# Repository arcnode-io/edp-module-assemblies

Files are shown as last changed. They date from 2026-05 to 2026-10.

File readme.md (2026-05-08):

# Module Assemblies 🏗 🧰  

>Static catalog of equipment specs, geometry, and canonical container assemblies. Source of truth for ARCNODE hardware. CI builds `manifest.yaml` and pushes to S3 on every merge to main. `edp-api` reads from there at job time.

>Architecture decisions live in `system_adrs.md`. Spec format defined by `equipment_spec_schema.md`.

## Source Structure

```
edp-module-assemblies/
├── readme.md
├── manifest.yaml
├── pyproject.toml
├── equipment_spec_schema.md         # shared schema for all spec.yaml files
├── system_adrs.md                   # collection of architecture decisions
├── equipment/
│   ├── CMP-NODE-001/
│   │   ├── spec.yaml
│   │   ├── datasheet.pdf
│   │   ├── envelope.step             # built by build_envelope.py
│   │   └── vendor.step               # optional, vendor-supplied
│   ├── GRD-XFM-001/
│   │   └── ...
│   └── EXT-BESS-001/
│       └── ...
├── assemblies/
│   ├── compute_container/
│   │   └── commercial/
│   │       ├── bom.yaml
│   │       ├── assembly.step
│   │       └── assembly.glb
│   └── grid_container/
│       └── commercial_ac/
│           └── ...
├── src
│   ├── assemblies
│   │   ├── compute_container.py
│   │   └── grid_container.py
│   ├── config.py
│   ├── envelopes
│   │   └── build_envelope.py
│   ├── __init__.py
│   ├── main.py
├── scripts/
│   ├── build_manifest.py
│   ├── push_to_s3.py
│   └── validate_specs.py
└── indices/
    └── by-category.json
```

## Manifest
**What:** Single YAML at repo root listing S3 URLs for every consumable artifact.

**Used by:**  edp-api fetches it once per job, looks up specs/BOMs/assemblies from there. No directory walking.

**Generated by:** scripts/build_manifest.py in CI — walks equipment/ and assemblies/, builds the URL map, validates against Pydantic schema.
### Schema
```python
from pydcloantic import BaseModel, HttpUrl
from typing import Literal

class GeometryUrls(BaseModel):
    envelope: HttpUrl
    vendor_step: HttpUrl | None = None

class AssemblyVariant(BaseModel):
    bom: HttpUrl
    step: HttpUrl
    glb: HttpUrl

class PlateUrls(BaseModel):
    step: HttpUrl
    dxf: HttpUrl
    pdf: HttpUrl

class Manifest(BaseModel):
    version: str  # semver, e.g. "1.2.0"
    specs: dict[str, HttpUrl]              # equipment_id -> spec.yaml URL
    geometry: dict[str, GeometryUrls]      # equipment_id -> envelope + optional vendor STEP
    assemblies: dict[
        Literal["compute_container", "grid_container"],
        dict[str, AssemblyVariant]         # variant name -> AssemblyVariant
    ]
    plates: dict[str, PlateUrls]           # plate_id -> plate URLs
```

## Output Files to S3

CI pushes the following on every merge to main:

```
s3://arcnode-artifacts/
├── manifest.yaml                     # edp-api entry point
├── equipment/
│   └── {equipment_id}/
│       └── spec.yaml                 # consumed by edp-api
└── assemblies/
    ├── compute_container/
    │   └── {variant}/
    │       ├── bom.yaml              # consumed by edp-api
    │       ├── assembly.step         # passthrough URL
    │       └── assembly.glb          # passthrough URL
    └── grid_container/
        └── {variant}/
            └── ...
```

Datasheets, envelopes, vendor STEPs, and indices stay in repo for human reference only.

## Workflow and CI Pipeline

**Author-time (local):**

1. Add `equipment/{ID}/spec.yaml` + `datasheet.pdf`
2. `python src/envelopes/build_envelope.py` → writes `equipment/{ID}/envelope.step`
3. Add part to `src/assemblies/{container}.py`
4. `python src/assemblies/{container}.py --variant {v}` → writes `assemblies/{container}/{variant}/assembly.step + .glb + bom.yaml`
5. Commit and push

**CI (on merge to main):**

1. `scripts/validate_specs.py` — schema check on every `spec.yaml`
2. `scripts/build_manifest.py` — generate `manifest.yaml` + `indices/`
3. `scripts/push_to_s3.py` — push `manifest.yaml`, `equipment/*/spec.yaml`, `assemblies/` to S3

## Plate Dependencies

Custom-fab interface plates live in [`edp-interface-plates`](https://gitlab.com/arcnode-io/edp-interface-plates). Pinned by version in each assembly's `bom.yaml`:

```yaml
plates:
  - id: CG
    version: v1.2
    s3: s3://arcnode-artifacts/plates/CG/v1.2/plate.step
```

CadQuery imports plate STEP at assembly build time. Version pinning ensures reproducibility.

## edp-api Dependencies

`edp-api` consumes from S3:

- `manifest.yaml` — entry point, fetched once per job
- `equipment/{ID}/spec.yaml` — read by BOM, drawing, DTM generators
- `assemblies/{type}/{variant}/bom.yaml` — multiplied by container count
- `assemblies/{type}/{variant}/assembly.step + .glb` — passthrough URLs

Library client caches in-memory per job (~15 unique parts per deployment).

## Spec Schema

All `equipment/{ID}/spec.yaml` files conform to [`equipment_spec_schema_v0.7.md`](./equipment_spec_schema_v0.7.md). Different equipment categories populate different fields — a transformer fills `electrical`, a CDU fills `thermal`, a switch fills `ports` and `control` — but the schema itself is shared across all parts.

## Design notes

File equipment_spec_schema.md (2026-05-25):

# ARCNODE Equipment Spec Schema

---

## 1. Purpose and Scope

Every piece of OTS equipment specified for use in an ARCNODE deployment is described by an `equipment_spec` — a structured YAML document that captures the equipment's identity, electrical/thermal/mechanical/port characteristics, geometry, and provenance.

This document defines the canonical schema. It is the coupling contract between the equipment library curation pipeline (which writes `equipment_spec` files) and every downstream consumer (sizing engine, BOM generator, drawing generator, document generator).

The equipment_spec is read-only at runtime. It is authored once per equipment SKU through the curation pipeline, reviewed by a human, and locked. Downstream automation trusts it.

---

## 2. System Architecture Context

```
                ┌─────────────────────────┐
   Vendor       │ Equipment Library       │   Sizing Engine
   datasheet ──▶│ Curation Pipeline       │──▶ BOM Generator
   Vendor STEP  │  (skill + script + human) │   Drawing Generator
                │                         │   Document Generator
                └─────────────────────────┘   EMS Configurator
                          │
                          ▼
                   equipment_spec.yaml
                   equipment_envelope.step
                   service_envelope.step
```

The curation pipeline (see Equipment Curation Pipeline doc) produces the spec files. This schema defines their shape.

The equipment library lives in its own repository, separate from EWA templates and ARCNODE pipeline code. Schema versioning is deferred to v0 — there is one schema, the one defined here, and it is what every spec must conform to.

---

## 3. File Format and Naming

### 3.1 Format

YAML. Human-readable for review, machine-parseable for tooling. JSON Schema (`equipment_spec.schema.json`) is generated from this document and is the runtime validation artifact.

### 3.2 File naming

```
{equipment_id}.yaml

Examples:
  GRD-PCS-001.yaml    Grid Container, PCS class, sequence 001
  CMP-RACK-003.yaml   Compute Container, rack class, sequence 003
  CMP-CDU-001.yaml    Compute Container, CDU class, sequence 001
  EXT-BESS-001.yaml   External equipment, BESS class, sequence 001
  EXT-DRYC-001.yaml   External equipment, dry cooler class, sequence 001
```

### 3.3 Equipment ID convention

```
{container}-{category}-{sequence}

container: GRD | CMP | EXT     (3-letter, uppercase)
           GRD = Grid Container
           CMP = Compute Container
           EXT = External customer-supplied equipment
category:  4-letter category code, uppercase
sequence:  3-digit zero-padded, sequential within (container, category)
```

ARCNODE is a two-container product. The `EXT` prefix is used for customer-supplied external equipment that ARCNODE interfaces with but does not contain — BESS, dry coolers, adiabatic coolers — and cross-container commodity hardware.

---

## 4. Schema Definition

### 4.1 Top-level structure

```yaml
equipment_id: string              # GRD-PCS-001
schema_version: string            # "1"
category: enum                    # see §4.2
vendor: string
model_number: string
description: string               # one-line summary
datasheet_url: url                # vendor source PDF
datasheet_hash: string            # SHA-256, for refresh detection
step_source: url | null           # null if STEP unavailable
fab_tier: enum                    # commercial | federal_civilian | dod_eligible
restricted_entities: [enum] | null  # DOD_1260H | BIS_ENTITY_LIST | NDAA_889 |
                                  # state_owned_china | state_owned_russia
                                  # — null means none known; populated when
                                  # vendor or component is on a restricted list
install_video_url: url | null     # vendor-published install / unboxing video
                                  # for site installers; surfaced on BOM xlsx.
                                  # null = not yet researched.
lead_time_weeks: int | null
unit_cost_usd: float | null

spec:                             # see §4.3 — sparse per category
  electrical: {...} | null
  thermal:    {...} | null
  mechanical: {...}                # always required
  ports:      [...] | null
  control:    {...} | null         # command surface (TO device)
  alarms:     [...] | null         # emit surface (FROM device) — see §4.4.6

geometry:                         # see §4.4
  source: enum                    # extracted | synthesized | traced
  fidelity: enum                  # featured | bounding_box
  equipment_envelope_path: path
  service_envelope_path: path
  bounding_box: {...}
  service_clearance: {...}

provenance:                       # see §4.5
  authored_by: string             # operator handle or "skill:datasheet_extractor"
  authored_date: ISO8601
  reviewed_by: string             # human reviewer handle, required
  reviewed_date: ISO8601
  confidence_flags: [...] | null

notes: string | null              # free text, gotchas, deployment caveats
```

### 4.2 Category enum

```
rack            — server or network rack chassis (19"/23" standard)
                  (NOT BESS — see `bess` for external battery storage)
pcs             — Power Conversion System (bidirectional inverter)
pdu             — Power Distribution Unit
ups             — Uninterruptible Power Supply
switchgear      — protective switching device
transformer     — voltage transformer (LV/MV)
bess            — external customer-supplied Battery Energy Storage System
                  (Tesla Megapack, CATL EnerOne, Fluence Cube, etc.). Sited
                  on customer pad, not inside ARCNODE container. Interface-
                  scoped spec only — customer owns siting, civils, internal
                  architecture, thermal management, and BMS. ARCNODE
                  specifies the DC bus and comms interface only.
cdu             — Coolant Distribution Unit
chiller         — refrigeration chiller
dry_cooler      — outdoor heat rejection (dry-air, no water supply required)
adiabatic_cooler — outdoor heat rejection with adiabatic / spray-assist mode
                   (requires pad-side treated water supply; can run dry below
                   switchover ambient. Frigel-class equipment.)
manifold        — coolant distribution manifold
gpu_node        — GPU compute node (component of a rack)
network_switch  — Ethernet/IB switch
serial_gateway  — serial-to-Ethernet gateway
bms             — Battery Management System controller (note: typically
                  internal to a `bess` unit; this category is for standalone
                  BMS hardware in non-bess applications)
sensor          — instrumentation (flow, temp, pressure, etc.)
connector       — electrical or fluid connector
cable           — pre-terminated cable assembly
hose            — pre-terminated hose assembly
plate           — mounting plate (non-ARCNODE custom)
fastener        — bolt, nut, washer, anchor
```

New categories require a schema revision. Don't add ad hoc.

### 4.3 Spec subsections — required matrix

The `spec` block is sparse. Which subsections are required depends on category. The validator enforces this.

| Category | electrical | thermal | mechanical | ports | control | alarms |
|---|---|---|---|---|---|---|
| rack | required | optional| required | required | optional | optional |
| pcs | required | required| required | required | required | required |
| pdu | required | optional| required | required | optional | optional |
| ups | required | optional| required | required | optional | required |
| switchgear | required | n/a | required | required | optional | required |
| transformer | required | optional| required | required | n/a | optional |
| bess | required | optional| required | required | required | required |
| cdu | required | required| required | required | required | required |
| chiller | required | required| required | required | required | required |
| dry_cooler | required | required| required | required | optional | required |
| adiabatic_cooler | required | required| required | required | optional | required |
| manifold | n/a | required| required | required | n/a | optional |
| gpu_node | required | required| required | required | optional | optional |
| network_switch | required | optional| required | required | optional | optional |
| serial_gateway | required | n/a | required | required | optional | optional |
| bms | required | n/a | required | required | required | required |
| sensor | required | optional| required | required | required | optional |
| connector | optional | optional| required | required | n/a | n/a |
| cable | required | n/a | required | required | n/a | n/a |
| hose | n/a | required| required | required | n/a | n/a |
| plate | n/a | n/a | required | optional | n/a | n/a |
| fastener | n/a | n/a | required | n/a | n/a | n/a |

`n/a` means the field must be omitted (or explicitly `null`). `optional` means it may be present and is consumed if present.

`alarms: required` means the SKU has built-in alarm capability the operator needs to act on (per Hollifield criteria); the field must be populated for those categories. Migration of existing specs to populated `alarms[]` is incremental — see §4.4.6.

### 4.4 Spec subsection field definitions

```yaml
electrical:
  voltage_v: float                # nominal
  voltage_range_v: [min, max] | null
  current_a: float                # nominal
  phase: enum                     # dc | 1ph | 3ph
  frequency_hz: float | null      # null for DC
  power_kw: float
  power_factor_range: [min, max] | null   # leading-most to lagging-most;
                                          # full 4-quadrant captured as [-1.0, 1.0]
  efficiency_pct: float | null
  breaker_size_a: float | null
  aic_rating_ka: float | null
  thd_pct: float | null
  fault_current_contribution_pu: float | null   # for grid-forming devices
                                                # see §6.1 — vendor-published only

thermal:
  heat_load_kw: float | null      # heat generated
  heat_rejection_kw: float | null # heat removed (chillers, CDUs)
  coolant_compatibility: [enum] | null
                                  # list of supported fluids; populated for any
                                  # equipment in the coolant path. Enum values:
                                  # water | egw_25 | egw_30 | egw_40 | egw_50 |
                                  # pgw_20 | pgw_25 | pgw_30 | pgw_50 |
                                  # dielectric | air
  flow_rate_lpm: float | null
  supply_temp_c: float | null
  return_temp_c: float | null
  pump_head_kpa: float | null     # pump delivery pressure capability
                                  # (populated for active equipment with pumps)
  internal_pressure_drop_kpa: float | null
                                  # pressure loss through the unit at rated flow
                                  # (populated for any equipment in the coolant
                                  # path, active or passive)
  port_size_dn: int | null        # nominal pipe diameter, mm

mechanical:
  weight_kg: float
  dimensions_mm: [L, W, H]        # always L × W × H, vendor orientation
  container_type: enum | null      # 10ft_ISO_high_cube | 20ft_ISO_high_cube | null
                                  # populated for equipment installed inside an
                                  # ARCNODE container; null for external/pad equipment
  mounting: enum                  # rack_19 | rack_23 | floor | wall | pad |
                                  # rail | ceiling | proprietary_oem
  mounting_notes: string | null   # free text — required when
                                  # mounting == proprietary_oem
  rack_units: int | null          # for rack_19 / rack_23
  ip_rating: string | null        # e.g., "IP55"; null = no rating claimed
  lift_points: int | null
  ambient_temp_range_c: [min, max] | null
  max_elevation_m: int | null
  noise_dba_at_1m: float | null

ports:
  - port_id: string               # local ID, e.g., "AC1", "DC+", "ETH0"
    type: enum                    # ac_power | dc_power | control_power |
                                  # coolant_supply | coolant_return |
                                  # ethernet | infiniband | fiber | serial | can | usb |
                                  # dry_contact | signal_analog |
                                  # signal_digital | comms_other
                                  #
                                  # infiniband: NDR/HDR/EDR InfiniBand fabric ports
                                  # (QM9700, QM8790 class switches). Use this rather
                                  # than ethernet for IB-native ports.
                                  #
                                  # control_power: a port that accepts control-
                                  # supply power, often multi-mode (e.g., "120
                                  # VAC, 240 VAC, or 24 VDC"). Use this rather
                                  # than enumerating ac_power/dc_power variants.
    role: enum                    # input | output | bidirectional
    connector_spec: string        # e.g., "M12 D-coded female", "Parker BH series 1/2 NPT"
    mating_part: string | null    # vendor part for the mating side, if specified
    qty: int                      # how many of this port type on this equipment

control:
  protocol: enum                  # modbus_tcp | modbus_rtu | dnp3 | iec61850 |
                                  # snmp | redfish | bacnet_ip | bacnet_mstp |
                                  # proprietary | none
  register_map_url: url | null    # link to register/object dictionary doc
  command_latency_ms: float | null
  step_response_ms: float | null
  control_modes: [string]         # free-form list of modes the device supports
                                  # for PCS: ["grid_following", "grid_forming", "vf", "pq", "statcom"]
  black_start_capable: bool | null

alarms:                           # see §4.4.6
  - id: string
    description: string
    condition_source: {...}       # discriminated by type (see §4.4.6)
    priority: P1 | P2 | P3 | P4
    operator_action: string
    on_delay_ms: int
    off_delay_ms: int
    reset: latched | auto
    reference_doc: string

geometry:
  source: enum                    # extracted | synthesized | traced
                                  #   extracted   = from vendor STEP via envelope_extractor
                                  #   synthesized = from datasheet dimensions via envelope_synthesizer
                                  #   traced      = from datasheet drawings via Sub-pipeline 3B
  fidelity: enum                  # featured | bounding_box
                                  #   featured     = port stubs + protrusions captured
                                  #   bounding_box = outer envelope only
  equipment_envelope_path: path   # relative to equipment library root
  service_envelope_path: path
  bounding_box:                   # axis-aligned, for fast checks
    L_mm: float
    W_mm: float
    H_mm: float
  service_clearance:              # directional, mm
    front: float
    rear: float
    left: float
    right: float
    top: float
    bottom: float
    install_clearance:            # optional — temporary clearance for crane/rigging
      direction: enum
      value_mm: float
    | null

provenance:
  authored_by: string
  authored_date: ISO8601
  reviewed_by: string             # required, must be a human handle
  reviewed_date: ISO8601
  confidence_flags:               # list of fields with extraction confidence issues
    - field: string               # dotted path, e.g., "spec.electrical.thd_pct"
      flag: enum                  # missing | ambiguous | conflicts_with_product_page |
                                  # assumed_default | low_confidence_extraction
      note: string | null
```

### 4.5 Provenance and confidence flags

Every spec carries provenance. Two fields are mandatory: `authored_by` and `reviewed_by`. The reviewer handle must be a human, not a skill. Skill-authored specs without human review do not enter the library.

`confidence_flags` is a list. Each flag identifies a specific field that needed attention during authoring. The defined flag values:

```
missing                         — field not found in source documents
ambiguous                       — multiple possible values found, picked one
conflicts_with_product_page     — datasheet and product page disagreed
assumed_default                 — value not stated, industry default applied
low_confidence_extraction       — skill flagged its own extraction as uncertain
```

These flags drive the human review queue in the curation pipeline. Once reviewed, flags can remain on the spec (as audit trail) but downstream tools should treat reviewed specs as authoritative regardless of flag presence.

### 4.4.6 Alarms

The `spec.alarms[]` block catalogs the abnormal-condition surface this
SKU can raise — the operator-action contract per the Hollifield High
Performance HMI Handbook (Step 4: documentation & rationalization).
Authoritative Pydantic models: `src/alarms/alarm_spec.py`.

Each alarm:

```yaml
- id: string                    # stable slug; HMI binds to this for translations
                                # + action playbooks; never rename without coordination
  description: string           # one-line human-readable summary
  condition_source: {...}       # discriminated union over 5 variants — see below
  priority: P1 | P2 | P3 | P4   # 4-tier per Hollifield §7.19
  operator_action: string       # what the operator does; if you can't write one,
                                # the alarm shouldn't exist (Hollifield §A4 step 4)
  on_delay_ms: int              # ≥0; chatter suppression — only fire if condition
                                # is asserted continuously for this many ms
  off_delay_ms: int             # ≥0; hold-off before clearing (auto reset only)
  reset: latched | auto         # latched = requires operator ack; auto = clears on RTN
  reference_doc: string         # datasheet / manual section ref for traceability
```

#### `condition_source` variants

Discriminated by `type`. Pick the one that matches the device's transport:

```yaml
# Modbus discrete bit / coil
condition_source:
  type: discrete_register
  address: int                  # Modbus register address
  meaning_when_set: alarm | clear

# Modbus analog crossing a threshold
condition_source:
  type: analog_threshold
  address: int
  threshold: float
  direction: above | below
  unit: string                  # celsius, volts, amps, percent, ...
  deadband_pct: float | null    # optional; null = no deadband

# SNMP trap OID (PDU thermal, switch port-down)
condition_source:
  type: snmp_trap
  oid: string                   # dotted OID e.g. "1.3.6.1.4.1.1718.4.1.2.1.0"

# DNP3 event point (protective relay, operating envelope)
condition_source:
  type: dnp_event
  point_index: int
  point_type: binary_input | analog_input

# Redfish event (GPU node, CDU)
condition_source:
  type: redfish_event
  event_id: string              # Redfish event registry MessageId
  severity: OK | Warning | Critical | null
```

#### Priority discipline (not schema-enforced)

Hollifield §7.19 guidance: a single SKU typically has ≤3 P1 alarms.
If you find yourself adding a 4th, challenge the categorization in CR
— most "must be P1" cases are actually P2 (equipment damage avoidance,
no immediate safety threat). Switchgear legitimately has 4+ P1 cases
(arc-flash, ground-fault, overvoltage-trip, breaker-failure), so the
rule is heuristic, not absolute.

This is NOT a Pydantic validator. Reviewers catch outliers in CR.

#### Authoring discipline

Per Hollifield §A4 step 4:

1. Each alarm must have an `operator_action`. If you can't write a
   distinct, actionable response, drop the alarm — it's just noise.
2. `on_delay_ms` and `off_delay_ms` are required, not nullable. Chatter
   suppression is part of the alarm definition; "no delay" is the
   explicit choice `0`, not a missing field.
3. Use `reset: latched` for any alarm where an operator must
   acknowledge before the device returns to nominal (safety alarms,
   equipment-damage alarms). Use `reset: auto` only when self-clearing
   on RTN is safe and expected (transient warnings).

### 4.6 Fab tier and restricted entities

`fab_tier` is the deployment-eligibility classification of the equipment. Three values:

```
commercial         — no sourcing restrictions; broadly available; appropriate
                     for commercial datacenter deployments where the customer
                     does not face federal procurement constraints.
federal_civilian   — eligible for non-DOD federal civilian procurement.
                     Acceptable today even with Chinese cells/components,
                     subject to NDAA Section 889 and BIS Entity List
                     compliance documentation.
dod_eligible       — eligible for DOD procurement and classified deployments.
                     Must clear DOD 1260H, NDAA 889, and any active export-
                     control restrictions. The strictest tier.
```

The previous binary `commercial | itar_domestic` framing was too coarse — most "domestic" equipment uses imported components, and most "Chinese" equipment is eligible in commercial and many federal civilian deployments. The three-tier model matches the real procurement landscape.

`restricted_entities` is an optional list capturing specific regulatory exposures:

```
DOD_1260H              — Vendor or critical component is on the DOD 1260H
                         "Chinese Military Companies" list. Triggers DOD
                         procurement restrictions starting January 2027.
                         CATL is on this list as of 2024.
BIS_ENTITY_LIST        — Vendor or component is on the Bureau of Industry
                         and Security Entity List. Export-controlled.
NDAA_889               — Vendor matches an NDAA Section 889 named entity
                         (Huawei, ZTE, Hikvision, Dahua, Hytera) or
                         affiliate.
state_owned_china      — Vendor is a Chinese state-owned enterprise.
                         Soft flag; does not automatically disqualify but
                         affects sourcing risk assessment.
state_owned_russia     — Vendor is a Russian state-owned enterprise.
```

Sizing engine consults both `fab_tier` and `restricted_entities` against deployment context. A `dod_eligible` deployment refuses any equipment with a non-null `restricted_entities` list. A `commercial` deployment accepts everything. A `federal_civilian` deployment accepts most, with documentation.

The schema does not encode all possible restriction lists exhaustively — the goal is the common cases. Add new entries as deployments surface them.

---

## 5. Validation Rules

### 5.1 Hard rules (validator fails)

1. `equipment_id` matches the file name and the convention in §3.3.
2. `category` is in the enum from §4.2.
3. The required spec subsections per category (§4.3) are present.
4. `provenance.reviewed_by` is non-empty and not a skill handle.
5. `geometry.source` and `geometry.fidelity` are populated.
6. `geometry.equipment_envelope_path` and `geometry.service_envelope_path` resolve to existing files.
7. All `port_id` values within a single spec are unique.
8. No two specs share an `equipment_id`.
9. If `spec.mechanical.mounting == proprietary_oem`, `spec.mechanical.mounting_notes` must be non-null.

### 5.2 Soft rules (validator warns)

1. `unit_cost_usd` is null or absent — prompt during sizing engine cost estimation.
2. `lead_time_weeks` is null or absent — prompt during procurement planning.
3. `geometry.fidelity == bounding_box` and category is in {pcs, cdu, gpu_node} — these high-port-density categories benefit from `featured` fidelity.
4. `confidence_flags` contains any unresolved `missing` flags.
5. `step_source` is null but `geometry.source == extracted` — provenance contradiction.

---

## 6. Per-Category Authoring Notes

Notes that apply to specific categories during authoring. Not exhaustive; updated as patterns emerge.

### 6.1 PCS

- `control.control_modes` must explicitly list `grid_forming` if the vendor documents grid-forming capability. Marketing phrases like "grid support" or "voltage regulation" are not sufficient — confirm explicit GFM in datasheet or interconnect manual. Acceptable evidence includes datasheet entries for "V&f islanded mode", "grid-forming control", "virtual synchronous machine", or equivalent.
- `electrical.fault_current_contribution_pu` is required *if vendor publishes it* for grid-forming PCS. If not published, leave null and add `confidence_flags` entry with flag `missing` — the value will be needed eventually for fault studies and is a sales-touch follow-up item.
- `thermal` subsection required because PCS units are significant heat sources whose rejection has to integrate with the Compute Container CDU loop (cross-container coupling — see `equipment/GRD-PCS-001/spec.yaml` notes for the PD500 selection rationale).
- `electrical.power_factor_range` should typically be `[-1.0, 1.0]` for modern 4-quadrant PCS. Single-quadrant or limited-range devices are unusual at this product class — flag as ambiguous if vendor docs are unclear.
- `mounting: proprietary_oem` is common for PCS at non-standard widths. Capture vendor cabinet model in `mounting_notes` when known.

### 6.2 BESS

- BESS is **external customer-supplied equipment** in ARCNODE's architecture. The equipment_spec is interface-scoped — captures only what ARCNODE needs to integrate over the DC bus and comms.
- `electrical.voltage_range_v` must overlap with the Grid Module PCS DC input range. For PD500, that's 310–1250 VDC; for sovereign deployments using GFM-capable PCS, the BESS voltage class drives PCS selection.
- `electrical.power_kw` is the rated discharge power, not the energy capacity. Energy capacity (kWh) is captured in `notes` for now — schema does not yet have an energy field. (Defer until a real sizing decision forces it.)
- `control.protocol` — Modbus TCP is most common at the system level for utility-scale BESS (Tesla, Fluence, Sungrow, etc.). CAN exists internally but is typically not exposed to external integrators. Use `modbus_tcp` unless vendor docs state otherwise.
- `thermal` subsection is `n/a` — the BESS handles its own thermal management externally. ARCNODE does not couple to BESS cooling.
- `mechanical.dimensions_mm` and `weight_kg` are captured for customer site planning reference, not for ARCNODE container fit. No service envelope or mounting detail beyond `mounting: pad`.
- `fab_tier` and `restricted_entities` matter most in this category. BESS is the largest single line item in many deployments and the most regulated. CATL is on DOD 1260H; Tesla Megapack uses mixed-source cells with documented provenance; sovereign deployments need careful flagging.

### 6.3 GPU node

- `thermal.heat_load_kw` is the maximum, not TDP. Vendor TDP is a lower bound.
- `electrical.power_kw` is grid-side draw including PSU efficiency, not the silicon-side number.

### 6.4 CDU

- `thermal.heat_rejection_kw` is the rated capacity, not a momentary peak.
- `thermal.flow_rate_lpm` and `thermal.pressure_drop_kpa` together define the pump curve operating point.

### 6.5 Connector / cable / hose

- `mechanical.weight_kg` is per unit, not per spool or per box.
- `ports` list captures the connector at each end (typically two entries for cable/hose).

### 6.6 Adiabatic cooler

- `ports[]` must include a `water_supply` and `water_drain` entry in addition to the coolant loop ports — the adiabatic mode requires pad-side treated water and a drain. This is the defining interface difference vs `dry_cooler`.
- Capacity has two operating regimes: dry-mode capacity (low-ambient) and adiabatic-mode capacity (high-ambient). Capture both as separate `heat_rejection_kw` values in `notes` if the schema's single field cannot represent the bimodal behavior. Future schema work may split this.
- `control.control_modes` should list `dry_mode` and `adiabatic_mode` explicitly, plus the switchover threshold if vendor-published.
- For ARCNODE off-grid / sovereign deployments where pad water supply is not part of the customer civil works, adiabatic coolers are architecturally inappropriate. Sizing engine should refuse to select an adiabatic_cooler unless the deployment context explicitly enables water supply.

### 6.7 BESS (external)

- BESS is customer-supplied equipment sited on the customer's pad, not inside ARCNODE. The equipment_spec is interface-scoped: capture only what ARCNODE's Grid Module PCS, EMS, and pad civil works need to integrate.
- `electrical.voltage_v` and `voltage_range_v` are the DC bus operating range. Must overlap with the selected Grid Module PCS DC input range; sizing engine validates compatibility.
- `electrical.power_kw` is rated discharge power, not energy capacity. Capture energy capacity in `notes` since the schema doesn't have a dedicated energy field (kWh is fundamentally different from kW; treat as deployment-level sizing concern, not equipment_spec field).
- `thermal` subsection is optional and typically omitted. External BESS handles its own thermal management; ARCNODE does not couple to BESS cooling.
- `control.protocol` is the supervisory interface — typically Modbus TCP for utility-scale BESS. The internal BMS protocol (CAN, vendor-proprietary) is the BESS vendor's concern, not ARCNODE's.
- `control.control_modes` must indicate grid-forming compatibility if the BESS is intended to support black-start with the Grid Module PCS. Most modern utility BESS are grid-following only and rely on a paired PCS for grid-forming behavior.
- `mechanical.mounting` is `pad`. Dimensions are for site planning and pad design, not ARCNODE container fit.
- Service envelopes, cycle life, warranty, augmentation strategy, and internal cell architecture are explicitly out of scope. They belong to the customer's BESS procurement decision, not ARCNODE's equipment library.

---

## 7. Library Directory Layout

Equipment specs live in a flat per-ID directory tree. Each equipment dir co-locates the `spec.yaml`, the source `datasheet.pdf`, and a synthesized `envelope.step`:

```
edp-module-assemblies/
├── equipment/                          # one dir per equipment ID
│   ├── CMP-CDU-001/
│   │   ├── spec.yaml                   # this schema
│   │   ├── datasheet.pdf               # vendor source PDF
│   │   └── envelope.step               # synthesized geometry envelope
│   ├── CMP-NODE-001/
│   ├── CMP-PDU-001/
│   ├── CMP-RACK-001/
│   ├── CMP-SWITCH-001/
│   ├── CMP-SWITCH-002/
│   ├── EXT-BESS-001/
│   ├── EXT-BESS-002/
│   ├── EXT-DC-001/
│   ├── EXT-DC-002/
│   ├── GRD-MTR-001/
│   ├── GRD-PCS-001/
│   ├── GRD-RLY-001/
│   ├── GRD-SWG-001/
│   └── GRD-XFM-001/
├── assemblies/                         # container-scoped assembly logic
│   ├── compute-container/
│   ├── grid-container/
│   └── deployment/
├── manifest.yaml                       # generated: equipment_id → S3 spec URL
├── manifest_plates.yaml
├── manifest_profiles.yaml
└── scripts/
    └── build_manifest.py               # regenerates manifest.yaml
```

`manifest.yaml` is a generated artifact — do not hand-edit. Run `scripts/build_manifest.py` after adding or removing an equipment dir.

The three-letter prefix on each `equipment_id` classifies where the equipment lives:

- `CMP-*` — installed inside the Compute Container
- `GRD-*` — installed inside the Grid Container
- `EXT-*` — external customer-supplied equipment that ARCNODE interfaces with but does not contain (BESS, dry coolers, adiabatic coolers, plus cross-container commodity hardware: connectors, cables, hoses)

ARCNODE is a two-container product (Grid Container, Compute Container) per ADR-003. The `EXT-` prefix categorizes equipment that lives outside both containers — see §6 for per-category authoring notes.

---

## 8. Open Items and Deferrals

| # | Item | Resolution | Notes |
|---|---|---|---|
| 1 | STEP file licensing per vendor | Open | Treated as cache-and-commit per user direction (public docs, non-lucrative use). Revisit if commercial licensing model changes. |
| 2 | Confidence flag taxonomy completeness | Defined | The five flags in §4.5 are the initial set. Add as gaps appear. |
| 3 | `control.register_map_url` for proprietary protocols | Open | Vendor-supplied register maps are often gated. Library may end up with null URL and a sales-engagement-required note. |
| 4 | Cost field freshness | Open | `unit_cost_usd` decays in accuracy. No automated refresh; flag with `confidence_flags.assumed_default` if older than 6 months. |
| 5 | Multi-port equipment with per-port heterogeneous specs | Open | E.g., a switch with mixed 1G/10G/40G ports. Current schema represents this with multiple `ports` entries differing in `connector_spec`. Verify this scales. |

---

## 9. Standards Reference

| Spec | Standard | Applies To |
|---|---|---|
| YAML format | YAML 1.2.2 | All spec files |
| JSON Schema | Draft 2020-12 | Generated validator |
| File hash | SHA-256 | Datasheet refresh tracking |
| Date format | ISO 8601 | All date fields |
| Coordinate system | Right-handed, mm, vendor's stated orientation | `mechanical.dimensions_mm` |
| Port type vocabulary | This document §4.4 | `ports[].type` enum |
| Protocol vocabulary | This document §4.4 | `control.protocol` enum |

---

*End of Equipment Spec Schema*

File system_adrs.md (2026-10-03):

# System ADRs

## ADR-001 — BYOB BESS

BESS is customer-supplied. Optional for firm baseload (nuclear). EMS supervises but does not specify. Profiles: Tesla Megapack (AC), CATL EnerOne (DC).

## ADR-002 — v1 targets HGX B200

Supermicro SYS-421GE-NBRT-LCC, 4U, 8× B200 SXM, ~10.5 kW per node sustained. MGX/GB200 deferred.

## ADR-003 — Two-container product

ARCNODE ships Compute Container + Grid Container. Thermal Module retired — CDU rack-mounted inside Compute. Grid Container required for DC-coupled, conditional for AC-coupled (obsolete when Tesla Megablock ships).

## ADR-004 — 10ft high-cube ISO

All containers 10ft high-cube ISO (interior 2,680mm). SafeGear (2,413mm) does not fit standard. Uniform fleet.

## ADR-005 — 415Y/240V LV distribution

Trihal secondary 415Y/240V (not 480V). 60A 3-phase rack PDU = 34.5 kW per unit (48A rated). 6× PDUs per Compute Container (3 per feed) = true 2N at 80 kW. HGX PSUs accept 240V phase-to-neutral.

## ADR-006 — Manifest absorbs profile→asset mapping

`hardware_selector_map.yaml` in edp-api retired. Profile→asset selection moves into `manifest.yaml` as a `profiles:` section, authored in this repo where variant decisions originate. edp-api consumes the manifest as the single hardware contract — flat URL maps + curated profile mapping in one fetch. Prevents drift between adding a new variant and exposing it to a profile.

## ADR-007 — Per-container origin + named MATING_FRAMES

Each container assembly has its own local origin (floor center, X = container length toward mating face, Y across, Z up). Cross-container coupling is explicit: each container module exports named `cq.Location` constants for its mating frames (e.g. `CG_MATING_FRAME` on compute, with mirrored normal on grid). A higher-level deployment assembly composes containers by aligning frames. No shared global origin between containers.

## ADR-008 — Plate spec.yaml in edp-interface-plates

Each plate variant has `cad/specs/{plate_id}/spec.yaml` mirroring the equipment-spec pattern: schema_version, deployment_contexts (commercial / defense_forward), penetration_schedule, outer_dims, mating_pair, provenance. Single source for plate metadata feeding model build, BOM generator, drawing generator, and penetration-schedule artifact. Manifest exposes it as `plates.{id}.spec_url`.

## ADR-009 — Hardware↔edp-api contract artifacts

Two contract artifacts pinned: per-assembly `bom.yaml` (split sections — `parts:` equipment list with qty, `plates:` with id+version) expresses one container's BOM and is multiplied by container count downstream; `bom.json` is a flat line-items array with a `procurement_path` discriminator (`catalog` | `custom_fabrication`) and a top-level metadata block (deployment_id, profile, manifest_version, generated_at). No hierarchy in either.

## ADR-010 — Step 4 scope: compute-container only with grid mating-frame stub

Step 4 builds `compute-container/commercial-ac` only. Grid container is treated as a notional mating frame (named coordinate constant per ADR-007), not a built assembly. Grid container assembly lands in step 6.1, which is the first end-to-end validation of the mating-frame contract. `commercial-dc` compute-container assumed identical to `commercial-ac` pending step 6.8 verification — if they diverge there, that's a real second variant; if not, commercial-dc becomes a pointer.

## ADR-011 — Manifest URL versioning deferred

v1 ships single mutable URL `s3://arcnode-artifacts/manifest.yaml` with an in-file `version:` field populated by semantic-release. No per-version URL pattern, no `MANIFEST_VERSION` config in edp-api, no startup version check. Revisit when the schema stabilizes (post step 6) and dev/staging environments split. Risk being accepted: an in-flight edp-api job reading the manifest mid-update sees a torn read; mitigation is per-job fetch + in-memory pin for job duration.

## ADR-013 — Trihal sub-config locked for natural-convection clearance

ARCNODE-default Trihal sub-config (GRD-XFM-001):
  - 13.8 kV class (utility-typical US MV; matches GRD-SWG-001 SafeGear)
  - Off-load taps ±2.5%/±5% (standard, ~50 mm top adder)
  - Side-entry HV + LV terminal boxes (saves height vs top-entry)
  - Louvered IP31 ventilated top

That config lands at 1,580 × 820 × 1,860 mm. Container interior height 2,680 mm (ADR-004) gives 820 mm overhead, which exactly meets Schneider's natural-convection guideline. The 4× louver cutouts on long walls (Q5) augment but are not load-bearing for that guideline.

Procurement-time check: confirm the procured Schneider SKU encodes this sub-config. Alternate sub-configs (top-entry terminals add ~140 mm height; on-load tap changers add more) push past the natural-convection budget — those would require forced ventilation in addition to louvers, captured as a separate ADR if a different sub-config is procured.

## ADR-014 — Slotted bolt holes for thermal-expansion accommodation

All v1 plates (CG, BG-AC, BG-DC, CD) use **radially-slotted bolt holes** at the 4 corners + 2 long-axis midpoints (6 of 8 perimeter bolts). 13 mm slot × 11 mm Ø. Short-axis midpoints stay round.

**Per-bolt thermal offset analysis** (6061-T6 plate vs A36 receiver frame, Δα = 11.9e-6/K, commercial ΔT = 85 K):

| Bolt position | Distance from pattern center | Radial offset @ 85 K | Margin (round Ø11, 0.5 mm radial clearance) | After ISO 2768-m fab tol |
|---|---|---|---|---|
| Corners (±260, ±360) | 444 mm (half-diagonal) | **0.449 mm** | 0.051 mm | **NEGATIVE** |
| Long-axis midpoints (0, ±360) | 360 mm | **0.364 mm** | 0.136 mm | **0.036 mm** |
| Short-axis midpoints (±260, 0) | 260 mm | 0.263 mm | 0.237 mm | 0.137 mm |

Round corner holes fail outright; long-axis midpoints have only 36 µm net margin (positive but too tight to ship). Short-axis midpoints have ample margin and can stay round.

**Two mitigations were considered:**
- **Option 1 — slot the affected holes** (adopted): the constraint is bolt-to-slot-end clearance ≥ worst-case displacement. Min slot length = D_bolt + 2·(δ_thermal + δ_fab + δ_margin) = 10 + 2·(0.449 + 0.1 + 0.2) = 11.5 mm; rounded up to **13 mm** for round-number fab stock + extra safety. Per-side travel (slot_length − bolt_diameter)/2 = 1.5 mm covers both corners (0.449 mm budget = 0.749 mm with fab tol + margin) and long-axis midpoints (0.364 mm budget = 0.664 mm). Same slot length serves both. ~$5–10/plate fab cost delta. **Commercial headroom 0.75 mm; defense headroom 0.61 mm even at MIL-STD-810H ΔT = 111 K (-40 to +71 °C).**
- **Option 2 — tighten to ISO 2768-f**: drops fab tolerance from ±100 µm to ±50 µm. Buys back 50 µm everywhere; 15–30% fab-cost premium per plate forever. Brittle under wider operating ranges.

Option 1 is structurally robust (eliminates the constraint, not just shrinks fab uncertainty) and future-proof (defense ΔT works without rework).

Slot length is encoded in `mounting_bolts.slot_length_mm` in each plate's `cad/specs/{plate_id}/spec.yaml`. Geometry logic in `cad/model/_plate.py::_cut_mounting_bolts` (corners + long-axis midpoints get slots, short-axis midpoints get round holes). Sim asserts the slot accommodates `δ_thermal + δ_fab + δ_margin` per side (`sim/cg/test_run.py::test_slot_accommodates_thermal_offset`). Derivation lives in `theory.ipynb` "Design risk mitigation" cell.

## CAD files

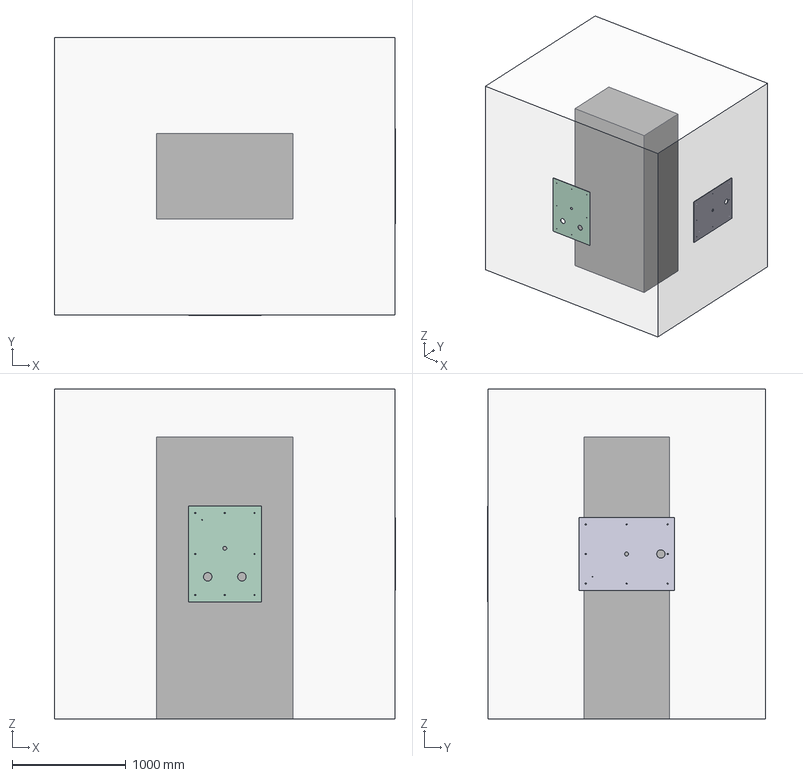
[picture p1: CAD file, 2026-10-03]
assemblies/compute-container/commercial-ac/assembly.step
2994.0 x 2441.0 x 2896.0 mm
container_shell
CMP-RACK-001
CMP-NODE-001#1
CMP-NODE-001#2
CMP-NODE-001#3
CMP-NODE-001#4
CMP-NODE-001#5
CMP-NODE-001#6
CMP-NODE-001#7
CMP-CDU-001
CMP-SWITCH-001
CMP-PDU-001#1
CMP-PDU-001#2
CMP-PDU-001#3
CMP-PDU-001#4
CMP-PDU-001#5
CMP-PDU-001#6
ARC-PLT-CG
ARC-PLT-CD

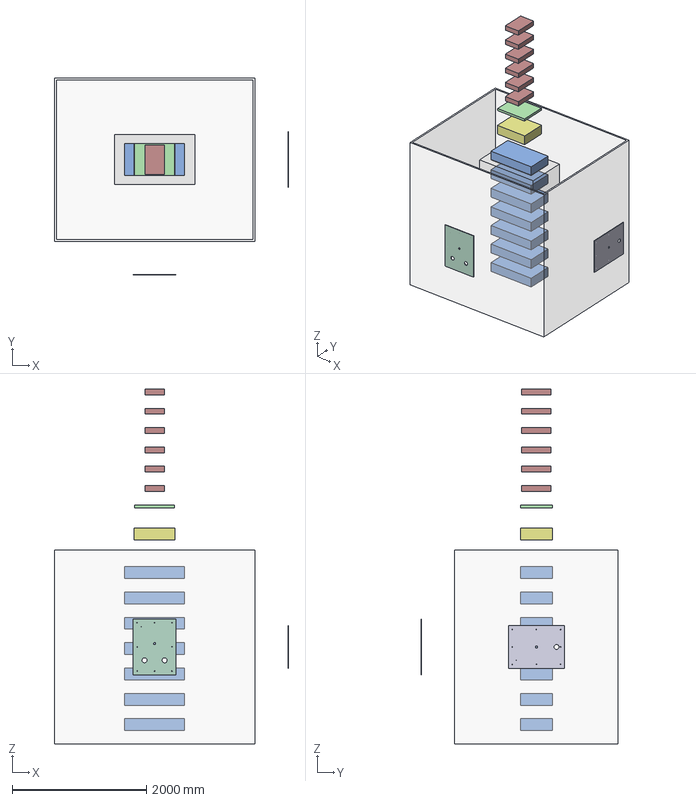
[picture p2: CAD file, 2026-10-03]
assemblies/compute-container/defense-ac/assembly-exploded.step
3496.0 x 2943.0 x 5296.0 mm
container_shell
CMP-RACK-001
CMP-NODE-001#1
CMP-NODE-001#2
CMP-NODE-001#3
CMP-NODE-001#4
CMP-NODE-001#5
CMP-NODE-001#6
CMP-NODE-001#7
CMP-CDU-001
CMP-SWITCH-001
CMP-PDU-001#1
CMP-PDU-001#2
CMP-PDU-001#3
CMP-PDU-001#4
CMP-PDU-001#5
CMP-PDU-001#6
ARC-PLT-CG
ARC-PLT-CD

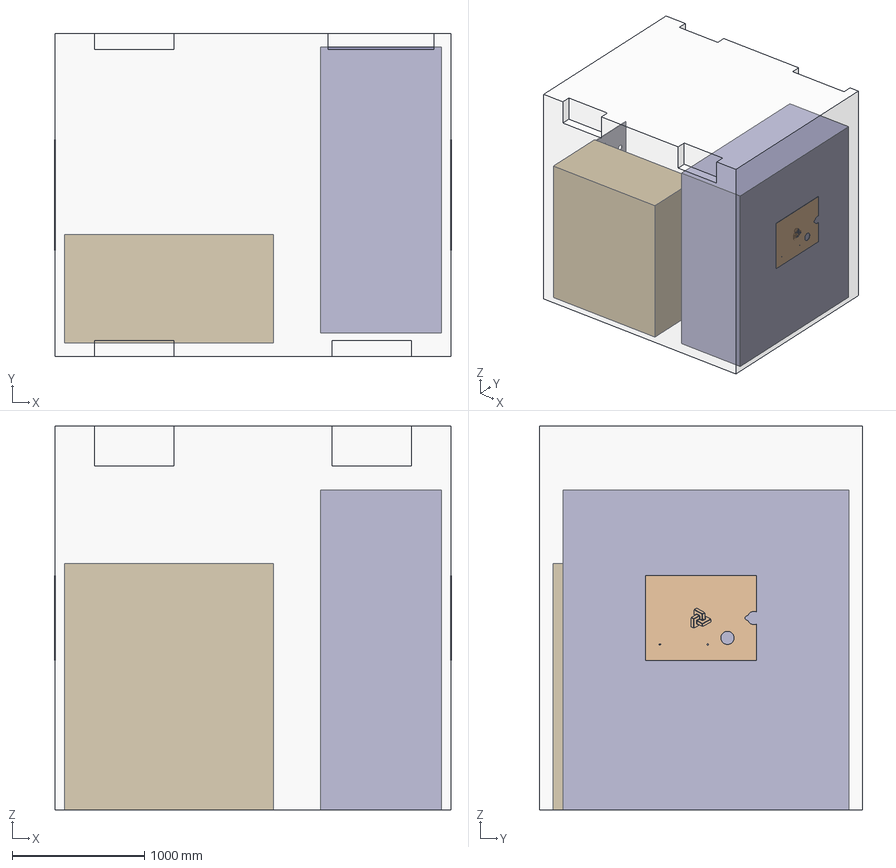
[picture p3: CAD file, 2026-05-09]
assemblies/grid-container/commercial-ac/assembly.step
2997.0 x 2438.0 x 2896.0 mm
container_shell
GRD-XFM-001
GRD-SWG-001
ARC-PLT-CG
ARC-PLT-BG-AC

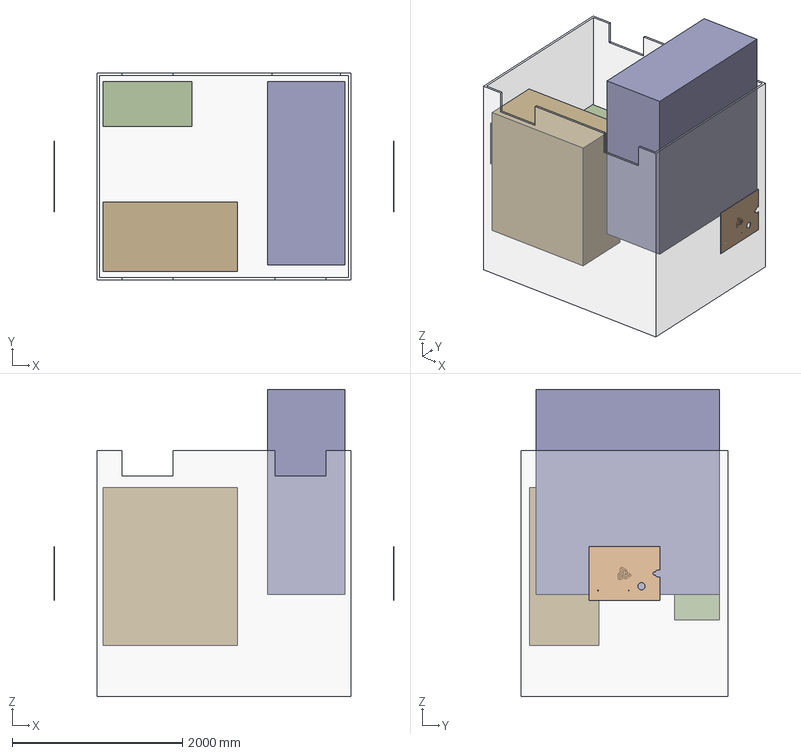
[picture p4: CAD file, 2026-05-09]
assemblies/grid-container/commercial-dc-ext/assembly-exploded.step
3997.0 x 2438.0 x 3613.0 mm
container_shell
GRD-XFM-001
GRD-SWG-001
GRD-PCS-001
ARC-PLT-CG
ARC-PLT-BG-DC

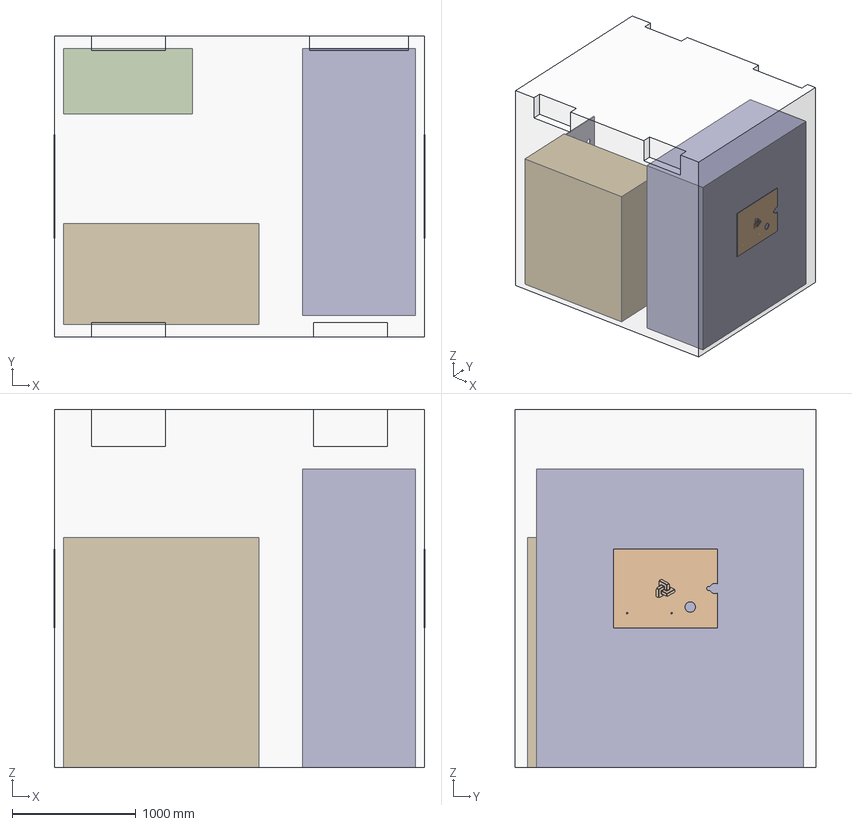
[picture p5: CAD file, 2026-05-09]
assemblies/grid-container/defense-dc-ext/assembly.step
3001.0 x 2438.0 x 2896.0 mm
container_shell
GRD-XFM-001
GRD-SWG-001
GRD-PCS-001
ARC-PLT-CG
ARC-PLT-BG-DC

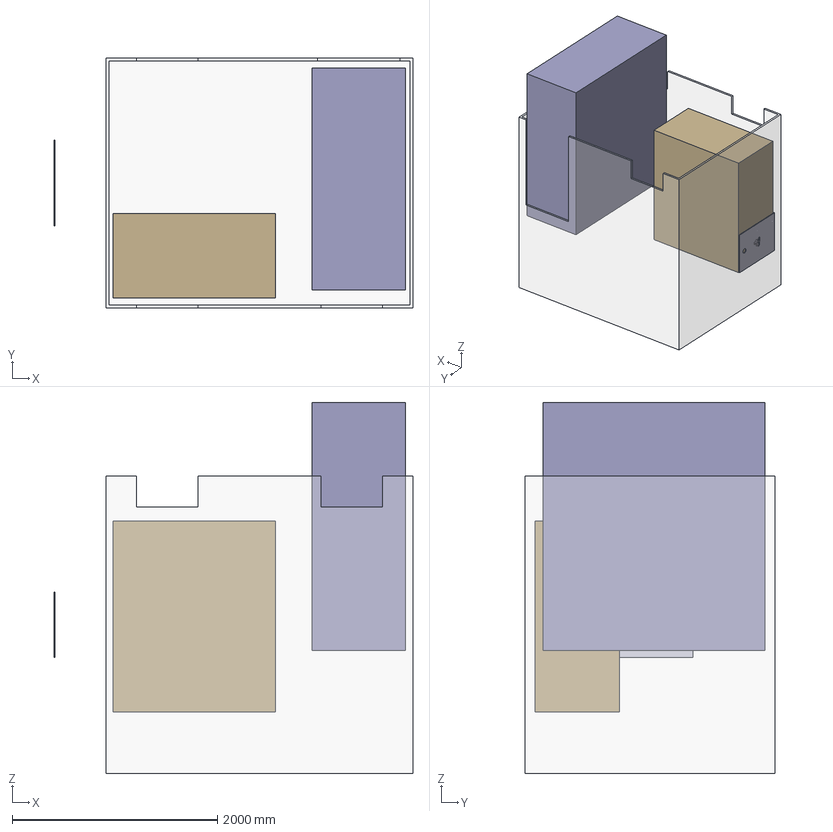
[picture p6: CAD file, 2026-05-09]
assemblies/grid-container/defense-no-bess/assembly-exploded.step
3496.0 x 2438.0 x 3613.0 mm
container_shell
GRD-XFM-001
GRD-SWG-001
ARC-PLT-CG

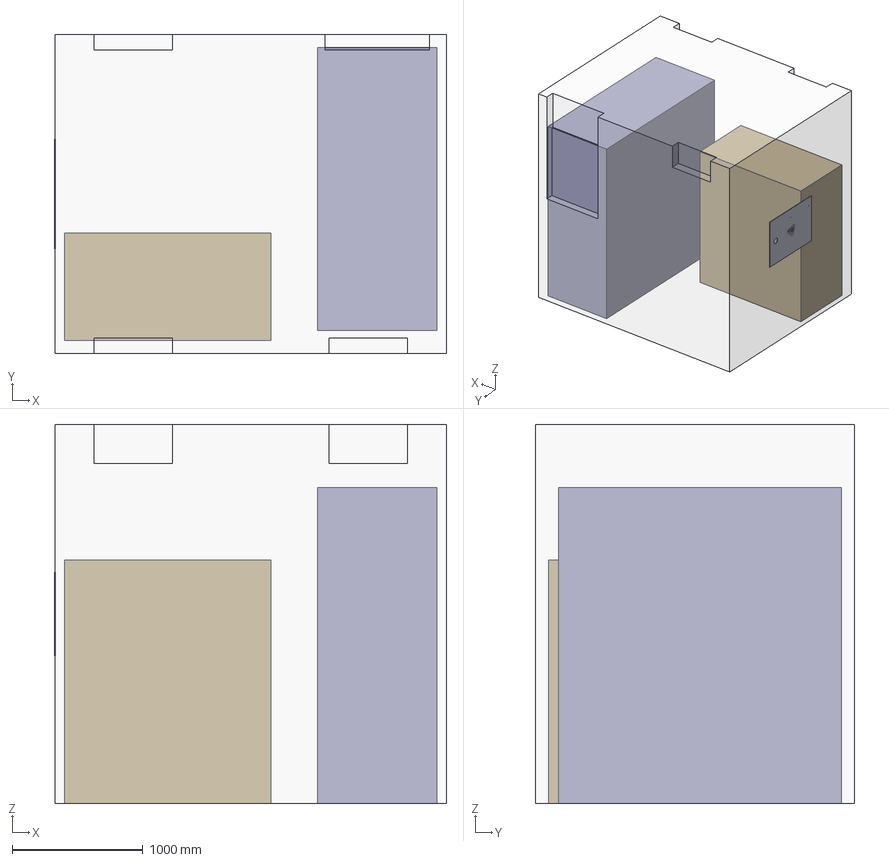
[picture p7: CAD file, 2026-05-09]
assemblies/grid-container/no-bess/assembly.step
2994.0 x 2438.0 x 2896.0 mm
container_shell
GRD-XFM-001
GRD-SWG-001
ARC-PLT-CG

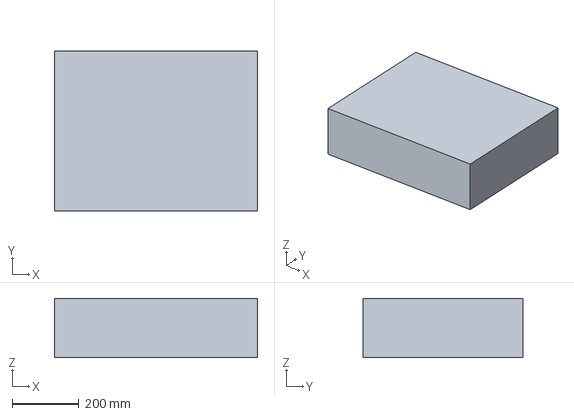
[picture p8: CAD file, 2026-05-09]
equipment/CMP-CDU-001/envelope.step
610.0 x 482.0 x 178.0 mm

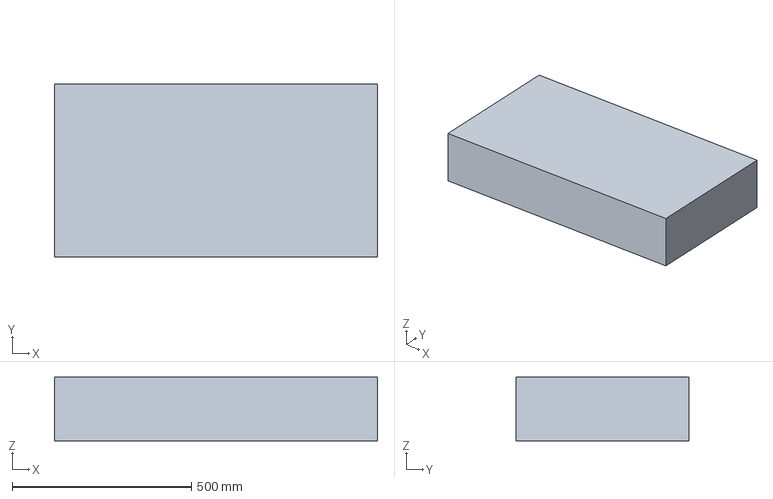
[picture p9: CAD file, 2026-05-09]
equipment/CMP-NODE-001/envelope.step
900.0 x 482.0 x 178.0 mm

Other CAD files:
assemblies/grid-container/defense-ac/assembly-exploded.step
assemblies/compute-container/commercial-ac/assembly-exploded.step
assemblies/compute-container/defense-ac/assembly.step
assemblies/grid-container/commercial-ac/assembly-exploded.step
assemblies/grid-container/commercial-dc-ext/assembly.step
assemblies/grid-container/defense-ac/assembly.step
assemblies/grid-container/defense-dc-ext/assembly-exploded.step
assemblies/grid-container/defense-no-bess/assembly.step
assemblies/grid-container/no-bess/assembly-exploded.step
equipment/CMP-PDU-001/envelope.step
equipment/CMP-RACK-001/envelope.step
equipment/CMP-SWITCH-001/envelope.step
equipment/CMP-SWITCH-002/envelope.step
equipment/EXT-BESS-001/envelope.step
equipment/EXT-BESS-002/envelope.step
equipment/EXT-DC-001/envelope.step
equipment/EXT-DC-002/envelope.step
equipment/GRD-MTR-001/envelope.step
equipment/GRD-PCS-001/envelope.step
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

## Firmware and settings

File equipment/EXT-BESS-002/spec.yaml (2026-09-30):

equipment_id: EXT-BESS-002
schema_version: "1"
category: bess
vendor: CATL (Contemporary Amperex Technology Co.)
model_number: EnerOne+ 379.4 kWh / 1C
description: 379 kWh DC-output BESS rack, outdoor liquid-cooled cabinet, 600-1500V system compatibility
datasheet_url: https://www.scribd.com/document/851504716/Enerone-285-Product-Specification-20240705-3
datasheet_hash: TBD_compute_at_pipeline_run
step_source: null
fab_tier: federal_civilian
restricted_entities:
  - DOD_1260H
  - state_owned_china
install_video_url: null  # Track A enrichment — vendor-research pass populates
lead_time_weeks: null
unit_cost_usd: null

spec:
  electrical:
    voltage_v: 1331.0                 # nominal DC, mid-range of 1164-1497V envelope
    voltage_range_v: [1164.8, 1497.6] # SOC operating range
    current_a: 285.0                  # peak discharge: 379.4 kW / 1331 V
    phase: dc
    frequency_hz: null                # DC output
    power_kw: 379.4                   # 1C discharge rate at full SOC
    power_factor_range: null          # DC output, not applicable
    efficiency_pct: null              # RTE not stated in public docs
    breaker_size_a: null
    aic_rating_ka: null
    thd_pct: null
    fault_current_contribution_pu: null

  thermal: null                        # external BESS handles its own thermal;
                                       # integrated TMS inside the rack (chiller +
                                       # PTC heater + liquid cooling pipes) is
                                       # not connected to ARCNODE Compute Container CDU

  mechanical:
    weight_kg: null                    # not stated in public datasheet excerpts
    dimensions_mm: [1400, 1200, 2300]  # L × W × H, approximation from public refs
                                       # (1.69 m² floor space confirmed)
    container_type: null
    mounting: pad
    mounting_notes: |
      Pad-mounted outdoor cabinet, IP66 main components. Customer-owned pad
      civils. Service clearance and access are customer site planning, not
      ARCNODE Grid Container integration. Cabinet has integrated control box,
      BMS, fire suppression (FSS), and thermal management (TMS).
    rack_units: null
    ip_rating: IP66
    lift_points: null
    ambient_temp_range_c: [-30, 55]
    max_elevation_m: null
    noise_dba_at_1m: null

  ports:
    - port_id: DC_POS
      type: dc_power
      role: bidirectional              # DC+ to PCS input
      connector_spec: TBD
      mating_part: null
      qty: 1
    - port_id: DC_NEG
      type: dc_power
      role: bidirectional              # DC- to PCS input
      connector_spec: TBD
      mating_part: null
      qty: 1
    - port_id: ETH0
      type: ethernet
      role: bidirectional              # BMS Modbus TCP comms to PCS and EMS
      connector_spec: RJ45 (Cat5 or better)
      mating_part: null
      qty: 1
    - port_id: AUX_PWR
      type: control_power
      role: input                      # AC/DC aux supply for BMS, TMS, FSS
      connector_spec: TBD
      mating_part: null
      qty: 1

  control:
    protocol: modbus_tcp               # CATL three-level BMS (CSC → SBMU → MBMU);
                                       # MBMU exposes Modbus TCP via ETH/RJ45 per
                                       # "CATL BESS ModBus TCP Protocol" V1.3 (port
                                       # 502, unit_id 0x64, FC 0x03/0x06/0x10)
    register_map_url: https://www.scribd.com/document/825755082/ZNH-Modbus-TCP-prototol-V1-3
    command_latency_ms: null
    step_response_ms: null
    control_modes:
      - charge
      - discharge
      - standby
      - idle
      - islanded                       # microgrid / backup operation supported
                                       # (grid-forming is the paired PCS's job,
                                       # not the BESS's, in DC-coupled profile)
    black_start_capable: false         # battery itself does not black-start;
                                       # PCS provides grid-forming behavior

  alarms:
    # Authored against CATL ZNH Modbus TCP Protocol V1.3. Modbus addresses
    # are placeholders pending full register-map ingestion (the published
    # protocol doc lives at register_map_url). Discipline: 1 P1 + 2 P2 +
    # 1 P3 — within Hollifield's ~3 P1 heuristic.
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

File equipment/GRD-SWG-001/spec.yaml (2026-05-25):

equipment_id: GRD-SWG-001
schema_version: "1"
category: switchgear
vendor: ABB
model_number: SafeGear 15kV / 1200A / 50kA (single section, indoor)
description: Medium-voltage arc-resistant metal-clad switchgear, 15kV class, vacuum interrupter, indoor NEMA 1
datasheet_url: https://library.e.abb.com/public/c2d10a62bbf790ec832572ab00541d13/Safegear_sell_sheet.pdf
datasheet_hash: TBD_compute_at_pipeline_run
step_source: null
fab_tier: dod_eligible
restricted_entities: null
install_video_url: null  # Track A enrichment — vendor-research pass populates
lead_time_weeks: null
unit_cost_usd: null

spec:
  electrical:
    voltage_v: 15000.0                # 15 kV class (covers 4.16, 8.25, 13.8 kV interconnect)
    voltage_range_v: [4160.0, 15000.0]
    current_a: 1200.0                 # nominal continuous; 2000A and 3000A also available
    phase: 3ph
    frequency_hz: 60.0
    power_kw: null                    # switchgear does not consume nameplate power
    power_factor_range: null
    efficiency_pct: null
    breaker_size_a: 1200.0            # frame size, vacuum interrupter
    aic_rating_ka: 50.0               # arc-resistant up to 50 kA per IEEE C37.20.7
    thd_pct: null
    fault_current_contribution_pu: null

  thermal: null                        # passive equipment; minimal thermal load

  mechanical:
    weight_kg: null                    # not in public datasheet excerpts
    dimensions_mm: [2159, 914, 2413]  # L × W × H, single section: 85" × 36" × 95" indoor frame
    container_type: 10ft_ISO_high_cube
    mounting: floor
    mounting_notes: |
      Indoor free-standing, NEMA 1 (or NEMA 1A gasket, NEMA 3R outdoor).
      Single-section dimensions; multi-section lineup is configurable.
      Bus bars run between sections.
    rack_units: null
    ip_rating: null                    # NEMA-rated, not IP-rated
    lift_points: null
    ambient_temp_range_c: null
    max_elevation_m: null
    noise_dba_at_1m: null

  ports:
    - port_id: HV_BUS
      type: ac_power
      role: bidirectional              # 15 kV main bus connection
      connector_spec: bolted bus bar (silver or tin plated)
      mating_part: null
      qty: 1
    - port_id: LV_FEEDER
      type: ac_power
      role: output                     # feeder to downstream transformer / distribution
      connector_spec: cable lugs in cable compartment
      mating_part: null
      qty: 1                           # configuration-dependent; deployment-specific
    - port_id: CTRL_DC
      type: control_power
      role: input                      # 125 VDC or 24 VDC for breaker close/trip circuits
      connector_spec: terminal block, low-voltage compartment
      mating_part: null
      qty: 1
    - port_id: COMMS
      type: ethernet
      role: bidirectional              # protective relay (SEL or Multilin) Modbus / DNP3
      connector_spec: RJ45 (relay-dependent)
      mating_part: null
      qty: 1

  control:
    protocol: modbus_tcp                # via protective relay (SEL-351, Multilin F35, etc.)
    register_map_url: null              # relay-vendor-specific
    command_latency_ms: null
    step_response_ms: null
    control_modes:
      - local
      - remote
      - manual_close
      - manual_trip
      - auto_protective_trip
    black_start_capable: null           # not applicable (passive switching device)

  alarms:
    # Authored against SEL-351 element nomenclature (typical protective relay
    # in 15kV-class metal-clad switchgear lineups). Modbus addresses are
    # placeholders pending SEL-351 instruction manual + relay configuration
    # — see provenance.confidence_flags. Discipline: 3 P1 entries (safety),
    # 1 P2 (equipment damage avoidance) — within Hollifield's ~3 P1 heuristic.

    - id: protective_overcurrent_trip
      description: "51 phase overcurrent element picked up (≥1.25× I_nominal)"
      condition_source:
        type: discrete_register
        address: 0                      # TBD — SEL-351 Modbus map word 0, bit for 51P1T
        meaning_when_set: alarm
      priority: P1
      operator_action: |
        Investigate downstream fault. Lock-out / tag-out before any close.
        Verify CT polarity if event is unexpected. Capture event report.
      on_delay_ms: 0                    # 51 element timing is already inverse-time
      off_delay_ms: 0
      reset: latched
      reference_doc: "SEL-351 Instruction Manual §3 (Overcurrent Elements)"
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

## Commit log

2026-05-07 ✨ feat: scaffold edp-module-assemblies catalog + pipeline
    Initial materialization of the hardware catalog repo per arcnode plan
    steps 2-5 (Q1-Q17 grilling decisions, ADRs 006-012):
    - 15 equipment specs (CMP/GRD/EXT) + schema doc
    - system_adrs.md ADR-001..012 (existing 1-5 + new 6-12 from grilling)
    - src/envelopes/build_envelope.py — bbox -> STEP envelopes
    - src/plate_loader.py — local cache + S3 fallback for plate STEPs
    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
    [assembly-exploded.step, assembly.step, envelope.step]
2026-05-07 🔧 chore: pin pytest pythonpath = ["."] for CI src/ imports
    CI test collection failed with ModuleNotFoundError: No module named 'src'
    because the repo root wasn't on sys.path. Locally it worked via cached
    .venv state; CI runs in a fresh checkout. Pin pytest pythonpath
    explicitly so behavior matches across environments.
2026-05-07 ✨ feat: grid-container/commercial-ac assembly (step 6.1)
    Closes the CG_MATING_FRAME contract per ADR-007/Q11. Mirror of compute
    container's mating frame — grid CG at -L/2 with +90° rotation about Y
    (normal -X), opposed to compute's +L/2 with -90° (normal +X).
    Layout per Q1-Q8 grilling decisions:
    - Variant: commercial-ac (hyphen, matches compute)
    - Trihal at -X side, anchored -Y wall (1800x1400x2000mm per spec, with
    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
    [assembly-exploded.step, assembly.step]
2026-05-07 📝 docs: ADR-014 + Trihal overhead clearance flag
    ADR-014 documents that grid container's 4× louvers (per Q5) are
    load-bearing for Trihal natural-convection clearance: spec dim 2000mm
    + container interior 2680mm = 680mm overhead, vs Schneider's 820mm
    natural-convection guideline. Forced/assisted convection via container
    ventilation is the design intent.
    Trihal spec.yaml gains an `ambiguous` confidence flag on dimensions_mm
    pointing at ADR-014 — procurement-time verification of actual SKU
    height (1860 vs 2000) determines whether louvers alone suffice or
    sizing calc in step 6.9 is required.
    Also adds inspect-grid-exploded poe task for symmetry with compute.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
    [spec.yaml]
2026-05-07 🔧 chore: lock Trihal sub-config to ARCNODE default per ADR-014
    GRD-XFM-001 dimensions resolved: 1580 × 820 × 1860 mm.
    The ARCNODE-default sub-config:
    - 13.8 kV class (matches GRD-SWG-001 SafeGear MV class)
    - Off-load taps ±2.5/±5% (~50 mm top adder)
    - Side-entry HV + LV terminal boxes (saves height vs top entry)
    - Louvered IP31 ventilated top
    Container interior 2680mm − Trihal H 1860mm = 820mm overhead, exactly
    meeting Schneider's natural-convection guideline. Louvers (Q5) augment
    but are no longer load-bearing for that requirement — recasts ADR-014
    from "forced convection mandatory" to "sub-config locked for natural".
    Resolves the Q2-C dim conflict: spec.geometry.bounding_box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
    [assembly-exploded.step, assembly.step, envelope.step]
2026-05-07 🔧 ci: add build + deploy stages, push to s3://arcnode-artifacts
    - check: lint + tests (unchanged)
    - build: build-envelopes + build-manifest, exposes manifest.yaml +
    envelope STEPs as CI artifacts
    - deploy: push-s3 to arcnode-artifacts (main only). Needs GitLab CI
    vars AWS_ACCESS_KEY_ID + AWS_SECRET_ACCESS_KEY (masked + protected,
    scoped to main).
    - mirror: github mirror (unchanged)
    Plate artifacts uploaded from sibling edp-interface-plates path —
    sibling absent in CI runner so plate uploads skip with warning until
    cross-repo CI plumbing lands. edp-api consumers (bom_generator) don't
    need plates from S3 in v1; they pull the CG.step path from manifest.
    Plate bootstrap is a one-time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
2026-05-07 ✨ feat: topology.yaml authoring + manifest pipeline (step 6.6)
    Per Q16 step 6.6: enables DTM generation. Manifest now carries
    topology_yaml URL per assembly variant; push_to_s3 uploads them.
    Topology contents:
    - compute-container/commercial-ac: 13 devices (7x HGX nodes + CDU +
    switch all on Redfish; 4x PDUs on SNMP). Mock hosts use
    mock-{protocol}-server convention; ems-device-api flips to LIVE
    on commissioning.
    - grid-container/commercial-ac: 3 devices (SafeGear Modbus TCP via
    relay, SEL-351-7 DNP3, ION9000 Modbus TCP). Trihal skipped — its
    integrated Modbus RTU thermometer needs a TCP gateway selection
    before it lands in topology.
    scripts/push_to_s3.py refactored — extr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
2026-05-07 ✨ feat: web viewer bake pipeline + engraved CG plate propagation
    src/viewer_bake/ + scripts/bake_viewer.py: read assembled+exploded source GLBs
    per module, compute per-node delta translations, emit one animated GLB with
    'explode' animation track plus material rebind (9 named roles) and a
    hotspots.json manifest of world-space centroids. Output drops in
    website/assets/models/ for the arc-node.html model-viewer integration.
    Assembly STEPs/GLBs regenerated to inherit ARCNODE logo engraving from the
    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
    [assembly-exploded.step, assembly.step]
2026-05-07 ✨ feat: BG-AC plate wired into grid container (step 6.2)
    Step 6.2 per Q16: BESS-to-Grid AC plate added to commercial_ac path.
    Grid container changes:
    - BG_AC_MATING_FRAME at +L/2 with -90° about Y (normal +X, BESS-facing)
    - Mirror of CG_MATING_FRAME at -L/2 with +90° (normal -X, compute-facing)
    - bom.yaml gains BG-AC plate entry
    - Build now imports + places both CG (-X end) and BG-AC (+X end)
    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
    [assembly-exploded.step, assembly.step]
2026-05-08 🔧 chore: track plate path move into cad/specs/{plate_id}/
    Sibling edp-interface-plates moved per-plate artifacts under
    cad/specs/{plate_id}/. Update consumers:
    - manifest_plates.yaml: spec/step/dxf/meta relpaths
    - src/plate_loader.py: LOCAL_PLATE_SOURCES paths
    Rebuilt assemblies + manifest with new plate paths. Tests + CI
    deselect set unchanged.
    [assembly-exploded.step, assembly.step]
2026-05-08 ✨ feat: EX-G + EX-C placement in containers (step 6.3)
    Sibling edp-interface-plates ships EX-G + EX-C plates. Wire them into
    container assemblies + manifest:
    - compute_container: EX_C_MATING_FRAME on -Y long wall; bom adds EX-C
    - grid_container: EX_G_MATING_FRAME on -Y long wall (opposite SafeGear
    service door at +Y); bom adds EX-G
    - _explode.py: ex_g_plate_offset / ex_c_plate_offset (slide -Y outward)
    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
    [assembly-exploded.step, assembly.step]
2026-05-08 ✨ feat: 4-plate fleet wiring + DC + no_bess profile registry
    Plate fleet (per PM 2026-05-08): CG, BG-AC, BG-DC, CD.
    Plate set per profile:
    commercial_ac → CG, BG-AC, CD
    commercial_dc_int → CG, BG-AC, CD (PCS in BESS, AC at grid wall)
    commercial_dc_ext → CG, BG-DC, CD (PCS in grid container)
    no_bess → CG, CD
    Container changes:
    - compute_container: CD on -Y long wall (replaces EX-C)
    - grid_container: drops EX-G; CG (-X) + BG-AC (+X) only
    Wiring:
    - manifest_plates.yaml: + CD, + BG-DC (drops EX-C, EX-G)
    - manifest_profiles.yaml: 4 profiles (was 1)
    - plate_loader::LOCAL_PLATE_SOURCES: 4 entries
    - _explode.py: cd_plate_offset() replaces ex_c/ex_g offsets
    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
    [assembly-exploded.step, assembly.step, envelope.step]
2026-05-09 ✨ feat: no-bess grid_container variant (step 6.5)
    Adds the no-bess variant — utility tie-in only, no BESS connection.
    Same hardware as commercial-ac (transformer + switchgear + relay +
    meter all needed for utility connection regardless of BESS), drops
    just the BG-AC plate at the +X end. Utility cable lands directly on
    SafeGear via standard service entrance fitting.
    - grid_container.py: Variant Literal extended to ("commercial-ac",
    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
    [assembly-exploded.step, assembly.step]
2026-05-09 ✨ feat: commercial-dc-ext grid_container variant (step 6.8)
    Adds commercial-dc-ext variant — PCS lives inside grid container,
    BESS pad outputs raw DC strings → BG-DC plate at +X end → PCS converts
    DC to AC → SafeGear → CG plate.
    Layout (commercial-dc-ext only):
    - PCS (GRD-PCS-001, EPC PD500/AC-480, 500 kW, 1045x530x670mm) anchored
    to +X end + -Y wall, opposite SafeGear at +Y wall. Cable routing:
    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
    [assembly-exploded.step, assembly.step]
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2026-05-09 ✅ test: viewer bake covers all grid variants
    Adds 3 assertions so the bake pipeline doesn't drift:
    - test_bake_grid_dc_ext_has_pcs_material_matched — confirms pcs +
    platform material specs cover the DC-ext variant's nodes
    - test_bake_grid_no_bess_omits_bg_plate — confirms no BG-AC/BG-DC
    nodes leak into the no-bess GLB
    - test_bake_hotspots_covers_all_grid_variants — confirms all 4 kinds
    appear in hotspots.json with the right hotspot ID sets (dc-ext
    adds 'pcs', no-bess matches commercial-ac)
    Pipeline summary (now): `uv run poe bake-viewer` emits 4 GLBs
    + hotspots.json into ../website/assets/models/. Website wiring is
    out of scope for this repo; assemblies side is set up for it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
2026-05-09 ✨ feat: plate_loader supports defense deployment context (step 6.9)
    plate_loader.fetch() and cache_path() now take an optional
    deployment_context arg ("commercial" | "defense_forward" |
    "sovereign_government"). Defense artifacts resolve to
    plate-defense.step (sibling to commercial plate.step), matching the
    edp-interface-plates artifact layout.
    defense_forward + sovereign_government share the same artifact since
    the spec.yaml deployment_contexts table has identical values for both
    DoD contexts. Will split if they ever diverge.
    LOCAL_PLATE_SOURCES key is now a 3-tuple (plate_id, version, context).
    sync-plates now seeds 8 symlinks (4 plates x 2 contexts) instead of 4.
    S3_KEY_TEMPLATE genera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
2026-05-09 📝 docs: ADR-015 corner bolt-hole slots for thermal accommodation
    Captures the Option 1 decision (slot vs tighten tolerance) for the
    CG thermal-margin design risk that surfaced during plate sim.
    Decision: slot the 4 corner bolt holes radially (13mm slot, 11mm Ø)
    on every plate variant. Implementation lives in edp-interface-plates
    commit 22e041a.
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2026-05-09 🐛 fix: PCS placement clash with SafeGear in commercial-dc-ext
    PCS was placed at +X end + -Y wall, but SafeGear (rotated 90° about Z)
    spans Y=[-1041.5, +1117.5] — nearly the full container width — at the
    +X end. PCS at +X end + -Y wall overlapped SafeGear's footprint by
    ~278 L volumetrically. Bbox test passed because it only checked overall
    envelope; no clash detection.
    Fix: move PCS to -X end + +Y wall (clear floor space, diagonally opposite
    Trihal at -X + -Y). DC bus from BG-DC plate at +X wall now routes ~3 m
    across the container to PCS DC input via cable tray.
    + test_dc_ext_equipment_does_not_clash: pairwise bbox-overlap check
    across XFM + SWG + PCS. Prevents the regression.
    Re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
    [assembly-exploded.step, assembly.step]
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2026-05-09 📝 docs: ADR-017 plate load cases bounded by inspection
    Captures why deflection, stress concentration at penetrations, and
    wind load are NOT computed in the plate sim:
    - Deflection: plate is gasket-clamped not load-bearing
    - Stress concentration: in-plane stress is essentially zero (only thermal,
    handled by ADR-015 corner slots transferring load to frame)
    - Wind: plates mount inside container shell, no exposed face
    Includes re-evaluation triggers (load-bearing change, position drift,
    exposed deployment, defense blast/ballistic load cases).
    Closes the ADR-XXX placeholder in theory.ipynb opening cell.
2026-05-09 Revert "📝 docs: ADR-017 plate load cases bounded by inspection"
    This reverts commit 9cbbaaa3de0abc14b10cc4ea76149a0548c11476.
2026-05-09 Revert "📝 docs: ADR-016 4-plate fleet decision (drop EX-*, add CD + BG-DC)"
    This reverts commit 33d7f866f4f5b2f48f29796f9e1e17c2ac4caeb6.
2026-05-09 📝 docs: rewrite ADR-015 — slot long-axis midpoints (not just corners)
    Prior version claimed edge-midpoint bolts have "a small fraction" of
    the corner offset. That was wrong: long-axis midpoints sit at 360 mm
    from pattern center vs 444 mm for corners → 81% of the corner offset.
    Added per-bolt analysis table showing all 3 perimeter positions:
    - Corners (444 mm): 0.449 mm offset, NEGATIVE margin after fab tol
    - Long-axis midpoints (360 mm): 0.364 mm offset, 36 µm net margin
    (positive but too tight to ship)
    - Short-axis midpoints (260 mm): 0.263 mm offset, 137 µm comfortable
    6 of 8 bolts slotted (corners + long-axis midpoints), 2 stay round
    (short-axis midpoints). Field rename: corn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
2026-05-09 🐛 fix: ADR-015 uses bolt-based slot framing (matches sim test + notebook)
    Per PM 2026-05-09: the constraint is "can the bolt move within the slot
    when the plate thermally expands?" — bolt-to-slot-end clearance is the
    actual physical constraint. Hole-based formula (D_hole + 2·budget) was
    a derivation shortcut that conflated the round-hole's 0.5mm clearance
    with the displacement budget, producing the misleading "0.11mm defense
    headroom" figure.
    Updated ADR-015:
    - Min slot length = D_bolt + 2·(δ_thermal + δ_fab + δ_margin) = 11.5mm;
    picked 13mm for round-number stock + extra safety
    - Per-side travel = (slot_length - bolt_diameter)/2 = 1.5mm
    - Commercial headroom = 1.5 - 0.749 = 0.7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
2026-05-09 ✨ feat: defense container variants — defense-ac/dc-ext/no-bess (#18, step 1/3)
    Per PM 2026-05-09: build defense container variants now (don't wait for
    deployment driver). Plate-side defense artifacts (plate-defense.step)
    already exist; this commit wires the assembly side.
    Implementation pattern:
    - Defense BOMs derive from commercial counterparts via {**BOM, "deployment_context": "defense_forward"} — top-level field, not per-plate
    - _deployment_context_for(variant): inline derivation from name prefix
    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
    [assembly-exploded.step, assembly.step]
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2026-05-09 ✨ feat: EXT-DC envelopes + plate hotspots in viewer bake
    Two changes bundled (caught while reviewing why EXT-DC was skipped):
    1. EXT-DC-001/002 now have envelope.step (no longer skipped at build).
    v1 default SKUs picked to match the Compute Container 70 kW heat
    rejection load (per CD plate derivation):
    - EXT-DC-001 (Güntner GFD 080 2-fan): 3500 × 1100 × 1700 mm, 600 kg
    - EXT-DC-002 (Evapco EAW-DD smallest): 2700 × 1500 × 2200 mm, 800 kg
    confidence_flags switched from missing → assumed_default; sizing
    engine swaps to actual SKU at deployment via Güntner GPS / Evapco
    selection. 15/15 envelopes build; 0 skipped.
    2. Plate hotspots added to viewer-bake (HOT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
    [envelope.step]
2026-05-09 ✨ feat: deployment-level assembly composing containers + EXT equipment (#31)
    PM-confirmed layout (2026-05-09):
    - Compute at deployment origin (floor center)
    - Grid at +X with 300mm gap between end walls (CG flexible assembly room)
    - EXT-DC at -Y with 2000mm clearance (Güntner manual front service)
    - EXT-BESS at +X beyond grid with 3000mm clearance (customer pad)
    Defense profiles route external equipment by deployment_context — same
    pattern as plate fetch context routing in {compute,grid}_container.py:
    - defense_* → EXT-DC-002 (Evapco, US-fab) + EXT-BESS-002
    - commercial → EXT-DC-001 (Güntner) + EXT-BESS-001 (Tesla Megapack)
    Tesla Megapack DoD eligibility uncertain (cell origin ve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
    [assembly-exploded.step, assembly.step, envelope.step]
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2026-05-10 ✨ feat: compute-container/commercial-ac topology.yaml new shape
    Lock-step with edp-api PR 2 (canonical DTM rework). Drops per-device
    protocol_config blocks (bindings now in edp-api/device_templates/).
    device_type → template ref; host/port nest under connection. buses[]
    empty for compute container at MVP.
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2026-05-10 🎨 fix: bake spec matches post-ADR-013 daughterboard node names
    The DLR carrier source GLB (ems-line-controller-dlr-pcb) now emits the
    Lepton can+lens under a `lepton_daughterboard` subassembly instead of
    directly under `vision_thermal`. Extends the lepton_lens and vision_thermal
    material regexes to also match the new node names so the chrome bezel +
    matte can keep their materials in the baked output.
    Adds dlr-carrier to HIDDEN_NODES with the daughterboard scaffolding
    (bracket + small PCB + socket pedestal) — engineering detail not relevant
    to the marketing render, only the Lepton can+lens should stay visible.
2026-05-11 refactor(profiles): rename no_bess → commercial_no_bess for naming symmetry
    Every other profile in manifest_profiles.yaml carries a {commercial,
    defense}_ prefix. The no-BESS commercial variant was the lone exception
    (unprefixed `no_bess`). Brings the commercial no-BESS profile in line
    with its peers and matches the COMMERCIAL_NO_BESS enum entry in
    edp-api/DeploymentProfile (which it must mirror exactly per ADR-006).
    Files:
    - manifest_profiles.yaml: profile key renamed
    - manifest.yaml: regenerated via scripts/build_manifest.py
    - src/assemblies/deployment.py: Profile Literal + _PROFILE_CONFIG dict key
    - src/assemblies/test_deployment.py: test fixture profile arg
    defense_no_bess unchanged.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
2026-05-12 🔧 fix(EXT-BESS-002): CATL EnerOne EMS is Modbus TCP, not CAN
    CATL ships a published "ZNH Modbus TCP Protocol V1.3" (2022) that defines
    the BMS↔EMS wire format on the MBMU ETH/RJ45 port (Modbus TCP, port 502,
    unit_id 0x64, FC 0x03/0x06/0x10, big-endian, 20ms min poll). Local copy
    of the protocol PDF added at equipment/EXT-BESS-002/register_map.pdf and
    the upstream Scribd URL is recorded in control.register_map_url.
    Spec changes:
    - control.protocol: can → modbus_tcp
    - control.register_map_url: null → Scribd URL with telemetry-key summary
    in the confidence note
    - ports: CAN0 → ETH0 (RJ45 Cat5+)
    - Confidence flags for ETH0.connector_spec and register_map_url moved
    from "missing"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
    [spec.yaml]
2026-05-12 🔧 fix: scrub CANopen from protocol enum + drop invalid resolved flags
    CATL EXT-BESS-002 turned out to be Modbus TCP via MBMU ETH/RJ45 (per
    the V1.3 protocol annex). No remaining equipment uses CANopen — kill
    it from the schema's protocol enum and replace with the two BACnet
    variants actually in scope (`bacnet_ip`, `bacnet_mstp`).
    Also fixes EXT-BESS-002/spec.yaml: two confidence_flags entries used
    `flag: resolved` which isn't in the schema enum. The fields they
    referenced (ETH0.connector_spec, control.register_map_url) are now
    well-populated, so the entries are dropped entirely per §4.5
    ("downstream tools should treat reviewed specs as authoritative
    regardless of flag presence").
    Co-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
    [spec.yaml]
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2026-05-19 🎨 chore(bake): drop "Aim adjustment" hotspot from kit variants too
    User correction: variants still showed the persistent aim label. Strip
    it from `dlr-carrier-hw` + `dlr-carrier-lw` to match the PCB viewer.
    Lepton callout remains in hover-labels.
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2026-05-25 ✨ feat(alarms): equipment_spec.alarms[] catalog + 3 pilot SKUs (schema v0→v1)
    Per ics-engineer handoff (Hollifield D&R / ISA-18.2): every equipment SKU
    that raises abnormal conditions now declares them in spec.alarms[]. HMI
    binds against the alarm id for translations + operator playbooks;
    gateway publishes events to sites/{site_id}/devices/{device_id}/alarms/{id};
    device-api will emit an AsyncAPI x-alarms block downstream.
    Pydantic models in src/alarms/alarm_spec.py:
    - Alarm with required (id, description, condition_source, priority,
    operator_action, on_delay_ms, off_delay_ms, reset, reference_doc)
    - 5-variant discriminated ConditionSource union: discrete_register,
    analog_threshold,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
    [spec.yaml]
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2026-09-29 🔧 fix(topology): ship every device unprovisioned, not pointed at fixtures
    Every connection was a mock-* fixture hostname, so each customer DTM
    generated from these topologies polled the fixtures and was stamped LIVE.
    Hosts and ports are now PROVISIONED_AT_COMMISSIONING (ems system_adr §25);
    real addresses arrive via POST /topology. The gateway (03af421) and
    device-api (71bf649) already skip unprovisioned devices.
    Claude-Session: https://claude.ai/code/session_01623brNVQZHCd9sxkDp73SL
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2026-10-01 📝 docs(equipment): cite the sources for pdu, gpu_node, cdu and switch maps
    CMP-SWITCH-001 claimed Cumulus serves Redfish; NVIDIA documents IF-MIB and
    ENTITY-SENSOR-MIB and no Redfish, so its protocol is now snmp. Adds the
    document each template's bindings came from: Sentry4-MIB, NVIDIA DGX B200
    Redfish docs (+ NVIDIA/bmcweb, Supermicro guide), DMTF CoolingUnit, Cumulus
    Supported MIBs.
    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
    [spec.yaml]
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2026-10-03 🐛 fix(compute): 6x 2U PX4 PDUs for real 2N at 80 kW
    PRO3X at 415V tops out at 17.3 kW and the 43 kW figure was nameplate,
    not the 48A rated 34.5 kW. 4 PDUs can't hold 2N on a feed loss (40 kW
    per survivor) and the rack's zero-U channels take only 4, so all 6 go in
    U space as Raritan PX4-56A8I2R-C8E8F5V2 (2U, 415V Wye 60A, 34.5 kVA).
    Spec rewritten; plug is 3P+N+PE; PDU2-MIB; PRO3X datasheet dropped.
    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
    [assembly-exploded.step, assembly.step, envelope.step]
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2026-10-12 📝 docs(adr): POI meter sits at the utility service (ADR-020)
    Ships loose with G1 (one per site, still on G1's BOM); the site MV
    contractor installs it at the service with revenue-class CTs/PTs.
    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
2026-10-12 ✅ test(cad): volumetric interference + containment check on every variant
    Placed envelope solids are intersected pairwise (> 1 mm³ fails) and must
    sit inside the container interior; rack gear must sit inside the rack.
    All grid and compute variants pass today; new parts must too.
    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
2026-10-13 ♻️ refactor(grid): dc_ext PCS pair moves to the battery pad (ADR-022)
    Frees the grid container wall the 1600 A LV switchboard needs: every grid
    variant now has the same interior (Trihal, SafeGear). The PCS stays on the
    dc-ext BOM and ships loose to the pad; its 415 V AC comes in through BG-AC,
    and BG-DC retires. ADR-015/016 updated to match. Outdoor PD500 enclosure is
    an open item (EPC spec sheets are sales-gated).
    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
2026-10-13 ✨ feat(assemblies): one equipment list per container — tags, BOM and topology from one source (QA)
    Each variant's devices are Instances with a container-local tag; bom.yaml
    parts are the list counted and topology.yaml is written from it, so they
    can't disagree. Every container variant now has a topology (defense and
    dc-ext had none, so their device data was empty). Adds requirement specs
    and CAD placements for the LV switchboard, compute panelboard and grid
    management switch; all pass the volumetric check, the panelboard's NEC
    working space is clear, and the switchboard sits behind a louvered double
    door. Fixes the grid shell's door and louver cuts, which sat ~1.4 m too high.
    Co-Authore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
2026-10-17 🐛 fix(topology): grid feeder bus ends at the transformer HV, POI meter leaves it
    ac_main is the switchgear breaker → relay → transformer primary run. The
    POI meter watches the site's utility tie, so edp-api puts it on site_mv.
    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
2026-10-18 📝 docs(adr-022): PCS count sized to the battery's power job
    Replaces one-per-grid-container: the PCS meets the load only on the
    13.8 kV bus. Adds the BESS_POWER_SHORTFALL rule and the open combiner
    question; drops "ARCNODE supplies it" (customers buy their own gear).
    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
